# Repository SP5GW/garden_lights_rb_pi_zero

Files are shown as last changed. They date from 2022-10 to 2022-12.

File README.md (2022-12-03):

**<p style="text-align: center;">GardenPi - The Garden Light Controller</p>**

<p align="center">
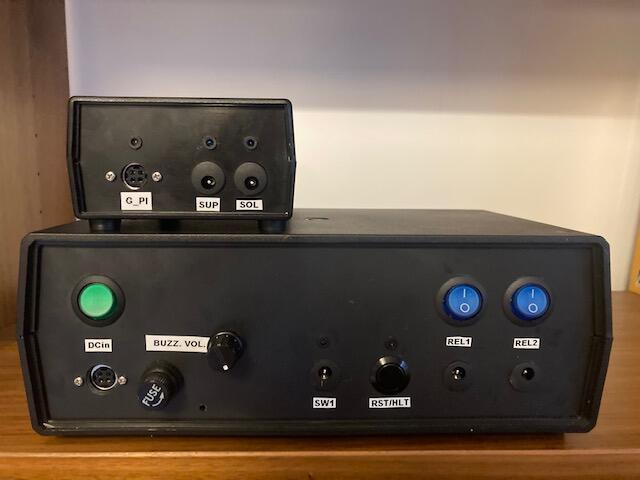
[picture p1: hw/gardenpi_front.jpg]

</p>

GardenPi is a Raspberry Pi Zero based two channel garden light controller, which includes hardware platform and systemd service written in python. Lights are automatically switched on/off based on calculated sunset time for provided location. Manual lights control is also supported. General information about status of the platform can be obtained from GUI and through cli command gardenpi, which also provides self diagnostics and remote logging configuration capabilities.

Platform is powered by:
<p align="left">
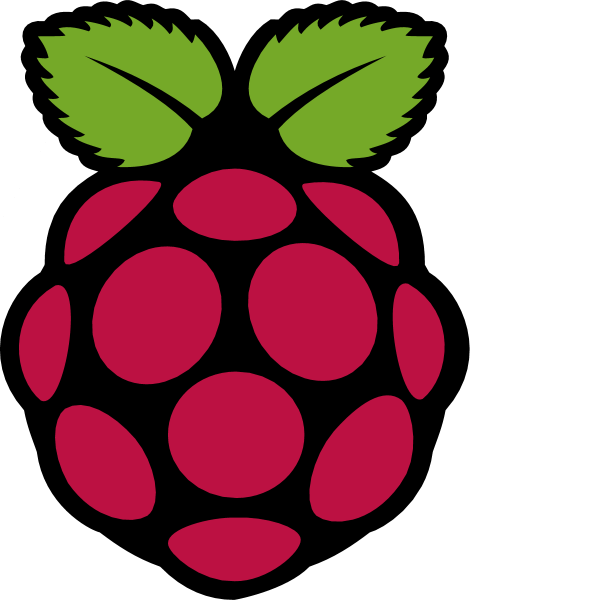
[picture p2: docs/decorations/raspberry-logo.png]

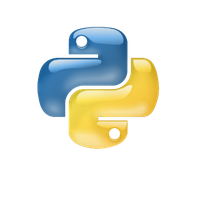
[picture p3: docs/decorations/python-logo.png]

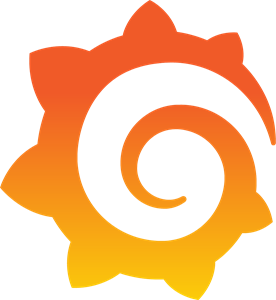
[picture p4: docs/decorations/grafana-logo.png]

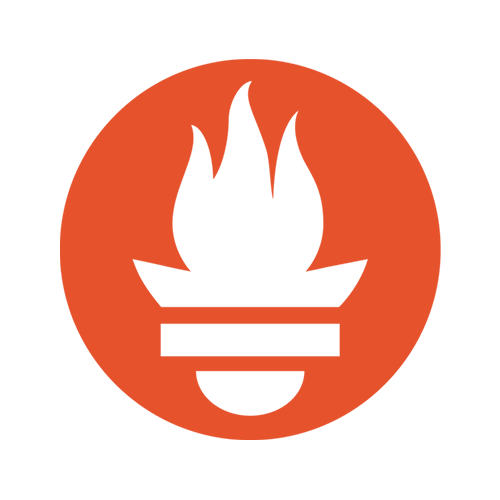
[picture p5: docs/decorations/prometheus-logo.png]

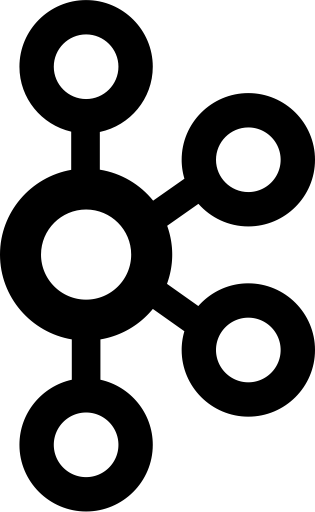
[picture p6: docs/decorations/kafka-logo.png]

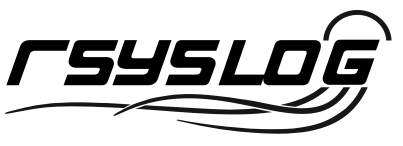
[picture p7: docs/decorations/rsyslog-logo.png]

</p>

**Key Features:**

- two software controlled relay 12V lighting channels with additional mechanical on/off switch (blue)
- main channel designated to control door lighting of the tool house
- secondary channel designated to control lighting of garden feature such as tree or sculpture
- both channels are switched on based on automatically calculated sunset time + predefined delay period
- main channel can be turned on with external on/off door switch as well
- configurable offset period controls delay between activation of main and secondary channel
- period when lights remain turned on can be configured separately for winter and summer time
- controller can be restarted by pressing Reset button
- controller can be shut down by toggling 5x the door switch within 1min interval
- door switch toggles are indicated by a beep.
- number of beeps correspond to the number of toggles, which occurred within 1min shutdown window
- after 1 min interval starting from the first switch on/off, toggle counter is reset to zero
- controller can be turned on and off by the green power switch
- when controller's boot sequence is finished after power on or restart, three short beeps are played 
- marked usb port can be used to ssh to the controller using cli command: ssh pi@gardenpi.local, pwd: raspberry
- wifi module is also configured and can be used whenever 2.4GHz wifi network is available
- real time is preserved at device shutdown using RTC module
- RTC module time is synchronized with network clock as soon as device is connected to LAN via Wi-Fi or USB
- Device is powered by 12V DC external power supplier (reversed polarity protection is implemented)
- Controller status is indicated by LED over RST/HLT button (steady/blinking - controller in operation)
- Grafana based simple GUI (dashboard) is available at http://gardenpi.local
- Simple unit diagnostics can be obtained by running command sudo gardenpi --test
- Buzzer volume can be controlled with potentiometer Buzz. Vol.
- Controller's syslog messages are forwarded to rsyslog server and kafka broker
- Remote logging enabled/configured/disabled using sudo gardenpi --logging option with parameters
- Power plug with additional digital line indicating source of power (solar vs. dc power supply) added
- Additional hardware unit switching automatically power source to dc power supply when battery voltage is too low released as a separate project (Solar / DC Backup Power Switch with Power Source Indicator). Unit is fully compatible with gardenpi controller version 5.0 and later.

**Design and Build Instructions**

HW design has been described in the following files:

* [Bill of Materials](./docs/gardenpi_bom.txt)
* [Circuit diagram](./docs/gardenpi_schematics.pdf)
* [HW Photos](./hw/)

Pi SW Image preparation process has been documented in the following command log file:

* SW Image Preparations command [log](./doc/gardenpi_cmd.txt).
* Latest stable SW image can be downloaded from [image repository](https://1drv.ms/u/s!AmoGY_QbIutmjDPu6R8zekghUcrf?e=fY6dYW)

Service python script, service file and initial configuration file storing service script settings are all located in:

* [Source Code Directory](./src)

All Pi configuration files, which were modified as part of this project are stored in:

* [Config Directory](./config)

**Initial Configuration**

* Connect GardenPi device to you linux host machine using usb cabel
* From host machine terminal ssh to GardenPi using following command:
	- ssh pi@gardenpi.local #password is set to: raspberry
* Modify solarcalc.ini  file with unit location information, all other parameters can be left at default.
	- nano ~/PyScripts/SolarCalc/solarcalc.ini
* Halt the device by toggling x5 door switch within 1min interval
* Unplug usb cable, place the device in target location and wire it to lighting and power source.
* If you need access to the list of config files and useful commands type gardenpi command.
* Enjoy the GardenPi device! :-)

**Device Operation**

Device does not require special maintenance, if GardenPi operates from location where there is no wifi access its RTC can drift so it is desirable to bring it within wifi coverage from time to time. Such behavior can be expected, but was not observed in real life yet.

**GUI**
Design of the GardenPi GUI has been detailed in gardenpi_gui.md document located in * [Docs Directory](./docs)
Grafana's dashboard has been specified in GardenPiController.json file located in * [Gui Directory](./gui)

GardenPi Dashboard:

<p align="center">
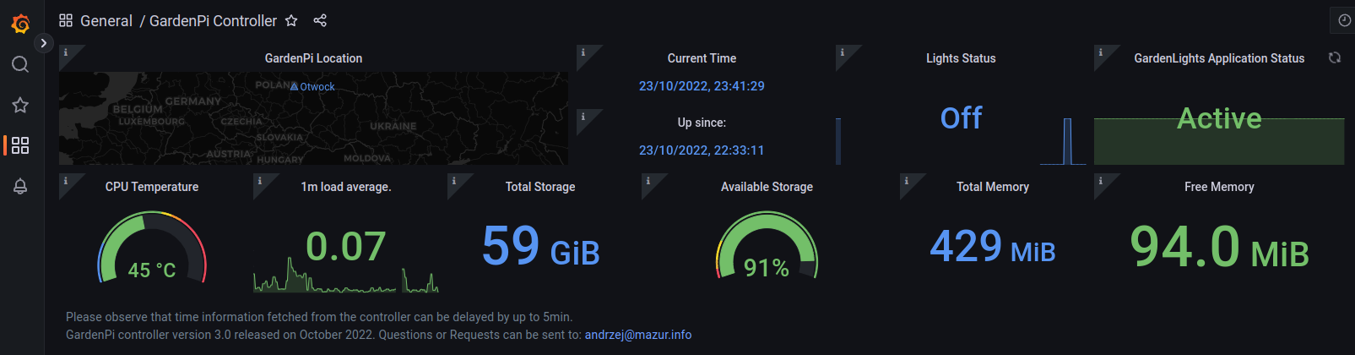
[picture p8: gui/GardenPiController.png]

</p>

**gardenpi command**
When connected to the terminal window over **ssh (user: pi@gardenpi.local, pwd: raspberry)**, it is possible to execute gardenpi command, which offers basic information about controller configuration.
To execute device selftest execute: **sudo gardenpi --test**

**Contributing**

* Fork it!
* Create your feature branch: git checkout -b my-new-feature
* Commit your changes: git commit -am 'Add some feature'
* Push to the branch: git push origin my-new-feature
* Submit a pull request

**Release History**

* Release 1.0 - October 2021 - basic functionality allowing light control
* Release 2.0 - October 2022 - new functionality:
	* device configuration via .ini file, 
	* buzzer support added, 
	* bug fixes focusing on stability (handling of shutdown procedure)
	* gardenpi command and device baner with useful configuration info added
* Release 3.0 - October 2022 - new functionality:
    * Grafana/Prometheus based GUI added
* Release 4.0 - October 2022 - new functionality:
	* 	buzzer volume control added
	* 	gardenpi command enhanced with device self-test routine
* Release 4.1 - November 2022 - new functionality and bug fixes:
	- possibility to set different lights-on durations for winter and summer times added
	- syslog messages are forwarded to rsyslog server and kafka broker
	- gardenpi command enhanced with remote logging configuration options
	* 	bug fix: depreciated zone function replaced in tzlocal with get_localtz_name() function call
	* 	bug fix: time presission correted in some info traces
* 	Release 5.0 December 2022 - new functionality:
	- 	Power connector changed to unique type, preventing accidental power cable incorrect insertion
	- 	Support for power source indicator (solar vs. power supply added)
	
**Planned Functionality**

* External WiFi antenna support
* Gardenpi service logging to syslog
* man page for gardenpi command

Comments or Questions can be directed to: andrzej@mazur.info

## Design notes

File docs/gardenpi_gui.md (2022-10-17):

# GardenPi GUI Implementation

<https://andrzejmazur2021.atlassian.net/wiki/spaces/~5ea827ff021ae30ba8e9fd23/pages/235470856/GardenPi+GUI+Implementation>

* * *

GardenPi GUI implementation is based on Grafana, Prometheus Node Exporter for arm v6 architecture and Prometheus Server. To screpe gardenlightsctrl.service Prometheus textfile data collector is used.



Due to current bug not allowing to change Grafana's TCP port number to 80 using grafana.ini file, port redirection from port 80 to 3000 using iptables has been configured instead.

## Prometheus Server Installation and Configuration

Check version of your arm architecture with: `cat /proc/cpuinfo`

```bash
cat cat /proc/cpuinfo
cat: cat: No such file or directory
processor	: 0
model name	: ARMv6-compatible processor rev 7 (v6l)
BogoMIPS	: 997.08
Features	: half thumb fastmult vfp edsp java tls 
CPU implementer	: 0x41
CPU architecture: 7
CPU variant	: 0x0
CPU part	: 0xb76
CPU revision	: 7

Hardware	: BCM2835
Revision	: 9000c1
Serial		: 00000000148e772f
Model		: Raspberry Pi Zero W Rev 1.1
```

In case of Pi Zero this is ARMv6.

Download Prometheus Server for your architecture from: [https://prometheus.io/download/](https://prometheus.io/download/) to your host machine, then copy it to your Pi Zero platform/PiGarden controller:

`scp /home/pi/Downloads/prometheus-2.39.1.linux-armv6.tar.gz pi@gardenpi.local:/home/pi`

Update all packages installed on the platform:

```bash
sudo apt update
apt list --upgradable
sudo apt upgrade
sudo shutdown -r now 
```

Extract the binaries outside of the archive you downloaded, move extracted directory to target location named `~/prometheus` and delete gz archive:

```bash
tar xfz prometheus-2.39.1.linux-armv6.tar.gz
mv prometheus-2.39.1.linux-armv6 prometheus
rm prometheus-2.39.1.linux-armv6.tar.gz
```

Create prometheus service file:

`sudo nano /etc/systemd/system/prometheus.service`

with following contents:

```bash
[Unit]
Description=Prometheus Server
Documentation=https://prometheus.io/docs/introduction/overview/
After=network-online.target

[Service]
User=pi
Restart=on-failure

ExecStart=/home/pi/prometheus/prometheus \
  --config.file=/home/pi/prometheus/prometheus.yml \
  --storage.tsdb.path=/home/pi/prometheus/data

[Install]
WantedBy=multi-user.target
```

Upon starting up, it will run the Prometheus executable located at “`/home/pi/prometheus/prometheus`“.

We pass in both the config file location and a storage location for the database that the monitoring software requires.

If you ever need to modify the config file, you can find it at “`/home/pi/prometheus/prometheus.yml`“.

Make prometheus service starting when Pi boots, then start the service manually and check its status:

```bash
sudo systemctl enable prometheus
sudo systemctl start prometheus
sudo systemctl status prometheus
```

Test prometheus service installation using curl:

## Prometheus Node Exporter Installation and Configuration

This time we use apt package installer to install Prometheus Node Exporter package:

```bash
sudo apt-get install prometheus-node-exporter
apt list --upgradable
sudo apt upgrade
```

Prometheus Node Exporter service file can be found at:

`/lib/systemd/system/prometheus-node-exporter.service`

Prometheus by default listens on port 9090, but we are interested in metricises from node exporter, which broadcasts data it scrapas on port 9100. That is why we need to reconfigure port number Prometheus Sever listens to and set it to 9100. This is done by the following modification of `~/prometheus/prometheus.yml` file in the following three areas:

```bash
global:
  #scrape_interval: 15s # Set the scrape interval to every 15 seconds. Default is every 1 minute.
  #evaluation_interval: 15s # Evaluate rules every 15 seconds. The default is every 1 minute.

  scrape_interval: 3s # Set the scrape interval to every 3 seconds. Default is every 1 minute.
  evaluation_interval: 3s # Evaluate rules every 3 seconds. The default is every 1 minute.

```

```bash
scrape_configs:
  # The job name is added as a label `job=<job_name>` to any timeseries scraped from this config.
  - job_name: "raspi"
```

```bash
    static_configs:
      #- targets: ["localhost:9090"]
      - targets: ["localhost:9100"]
```

To confirm that Prometheus Server is now receiving metrics' from Node Exporter execute the following command, which shall received cpu related metrics’:

```bash
curl http://localhost:9100/metrics | grep node_thermal_zone_temp
  % Total    % Received % Xferd  Average Speed   Time    Time     Time  Current
                                 Dload  Upload   Total   Spent    Left  Speed
100  130k    0  130k    0     # HELP node_thermal_zone_temp Zone temperature in Celsius
0 # TYPE node_thermal_zone_temp gauge
 node_thermal_zone_temp{type="cpu-thermal",zone="0"} 64.27
 529k      0 --:--:-- --:--:-- --:--:--  529k
```

If port Prometheus Server listens to is not changed correctly then no node\_ metrics' will be possible to fetch with curl…

Since we will need to report some gardenpi specific metrics' generated by `gardenlightsctrl.service` lets use for it textfile data collector of Prometheus Node Exporter. This collector is enabled by default and it scrapes all metrics' from files with .prom extension, which are located in the following directory:

`/var/lib/prometheus/node-exporter/`

More information regarding this data collector is available at: [https://github.com/prometheus/node\_exporter](https://github.com/prometheus/node_exporter)

To store metrics' specific to gardenpi lets create the following .prom file and make a symbolic link to it from `/var/lib/prometheus/node-exporter/` directory:

```bash
touch /home/pi/PyScripts/SolarCalc/solarcalc.prom
sudo ln ./solarcalc.prom /var/lib/prometheus/node-exporter/gardenpi.prom
```

Update contents of created solarcalc.prom file with simple test matrics:

`nano /home/pi/PyScripts/SolarCalc/solarcalc.prom`

```bash
# HELP gardenpi_lights_state Lights on/off indicator.
# TYPE gardenpi_lights_state gauge
gardenpi_lights_state 1
```

To verify that gardenpi metrics' are exposed to Prometheus Server:

```bash
ls -al /var/lib/prometheus/node-exporter/
total 12
drwxr-xr-x 2 root       root       4096 Oct 16 21:43 .
drwxr-xr-x 3 prometheus prometheus 4096 Oct 16 17:43 ..
-rw-r--r-- 1 root       root        397 Oct 16 21:43 apt.prom
-rw-r--r-- 2 pi         pi            0 Oct 16 21:41 gardenpi.prom
```

```bash
curl http://localhost:9100/metrics | grep gardenpi
  % Total    % Received % Xferd  Average Speed   Time    Time     Time  Current
                                 Dload  Upload   Total   Spent    Left  Speed
100  3944    0  3944    0     0   2409      0 --:--:--  0:00:01 --:--:--  2410# HELP gardenpi_lights_state Lights on/off indicator.
# TYPE gardenpi_lights_state gauge
gardenpi_lights_state 1
node_textfile_mtime_seconds{file="gardenpi.prom"} 1.66594986e+09
100  115k    0  115k    0     0  67378      0 --:--:--  0:00:01 --:--:-- 67378
node_uname_info{domainname="(none)",machine="armv6l",nodename="gardenpi",release="5.15.61+",sysname="Linux",version="#1579 Fri Aug 26 11:08:59 BST 2022"} 1
```

## Grafana Installation (RB PI4)

Add the APT key used to authenticate packages:

`wget -q -O - https://packages.grafana.com/gpg.key | sudo apt-key add -`

Add the Grafana APT repository:

`echo "deb https://packages.grafana.com/oss/deb stable main" | sudo tee -a /etc/apt/sources.list.d/grafana.list`

Install Grafana:

```bash
sudo apt-get update
sudo apt-get install -y grafana
```

Enable the Grafana server so it always starts after gardenpi is booted:

`sudo systemctl enable grafana-server`

Start the Grafana server:

```bash
sudo systemctl start grafana-server
sudo systemctl status grafana-server
```

Grafana is now running on the machine and is accessible from any device on the local network. it is accessible from host machine browser under the address: `gardenpi.local:3000`

Default grafana’s login credentials to be used during first login are: user: admin, password: admin

## Grafana Installation (RB PI Zero)

Uninstall grafana package installed with apt package manager (with all config files):

```bash
sudo apt purge grafana
sudo rm -rf /etc/grafana
```

Execute installation procedure from grafana web page for arm6 version: [https://grafana.com/grafana/download?platform=arm](https://grafana.com/grafana/download?platform=arm)

```bash
sudo apt-get install -y adduser libfontconfig1
wget https://dl.grafana.com/enterprise/release/grafana-enterprise-rpi_9.2.0_armhf.deb
sudo dpkg -i grafana-enterprise-rpi_9.2.0_armhf.deb
```

Enable the Grafana server so it always starts after gardenpi is booted:

```bash
sudo systemctl daemon-reload
sudo systemctl enable grafana-server
```

Start the Grafana server:

```bash
sudo systemctl start grafana-server
sudo systemctl status grafana-server
```

Grafana is now running on the machine and is accessible from any device on the local network. it is accessible from host machine browser under the address: `gardenpi.local:3000`

Default grafana’s login credentials to be used during first login are: user: admin, password: admin

At first login password has to be changed for admin user. new password is set to raspberry.

## Grafana Configuration

Due to current bug not allowing to change Grafana's TCP port number to 80 using grafana.ini file, port redirection from port 80 to 3000 using iptables has been configured instead.

iptables rules allowing grafana gui to be reached from browser on http port 80 following rules needs to be added:

redirection from outside world:  
`sudo iptables -A PREROUTING -t nat -i wlan0 -p tcp --dport 80 -j REDIRECT --to-port 3000`

redirection on the same machine:  
`sudo iptables -t nat -A OUTPUT -o lo -p tcp --dport 80 -j REDIRECT --to-port 3000`

In order to save new iptables rules `iptables-persistent` package has to be installed:

`sudo apt-get install iptables-persistent`

To list currently defined iptables rules for ipv4:

`nano /etc/iptables/rules.v4`

Content of above file after implementing port 80 to 3000 redirection:

```bash
# Generated by iptables-save v1.8.7 on Sun Oct 16 23:55:46 2022
*nat
:PREROUTING ACCEPT [0:0]
:INPUT ACCEPT [0:0]
:OUTPUT ACCEPT [0:0]
:POSTROUTING ACCEPT [0:0]
-A PREROUTING -i wlan0 -p tcp -m tcp --dport 80 -j REDIRECT --to-ports 3000
-A OUTPUT -o lo -p tcp -m tcp --dport 80 -j REDIRECT --to-ports 3000
COMMIT
# Completed on Sun Oct 16 23:55:46 2022
```

After adding new rules either directly to the file abbove `COMMIT` line or through `iptables` command. The new rules set can be saved with:

```bash
sudo su -
root@raspberrypi:~# sudo iptables-save > /etc/iptables/rules.v4
root@raspberrypi:~# exit
```

Login to grafana’s gui:

```bash
http://gardenpi.local
user: admin
password: raspberry
```

Go to admin panel, click bottom left shield icon and define pi user with no admin privileges:

```bash
user: pi
password: raspberry
```

Go to configuration, data sources and select Prometheus.

From Prometheus Datasource configuration panel the only place to make an adjustment is Prometheus server address:



Go to Dashboards, new, import and select to import from json file. Point at `./gui/GardenPiController.json`

Set imported gui as favourite (star in top left section of the gui)

Got to Configuration, Preferences and set home dashboard to GardenPi/GardenPi Controller:



## References

[https://prometheus.io/docs/introduction/overview/](https://prometheus.io/docs/introduction/overview/)

[https://pimylifeup.com/raspberry-pi-prometheus/](https://pimylifeup.com/raspberry-pi-prometheus/)

[https://github.com/prometheus/node\_exporter](https://github.com/prometheus/node_exporter)

[https://grafana.com/tutorials/install-grafana-on-raspberry-pi/](https://grafana.com/tutorials/install-grafana-on-raspberry-pi/)

[https://grafana.com/grafana/download?platform=arm](https://grafana.com/grafana/download?platform=arm)

[https://blog.mxard.com/persistent-iptables-on-raspberry-pi-raspbian](https://blog.mxard.com/persistent-iptables-on-raspberry-pi-raspbian)

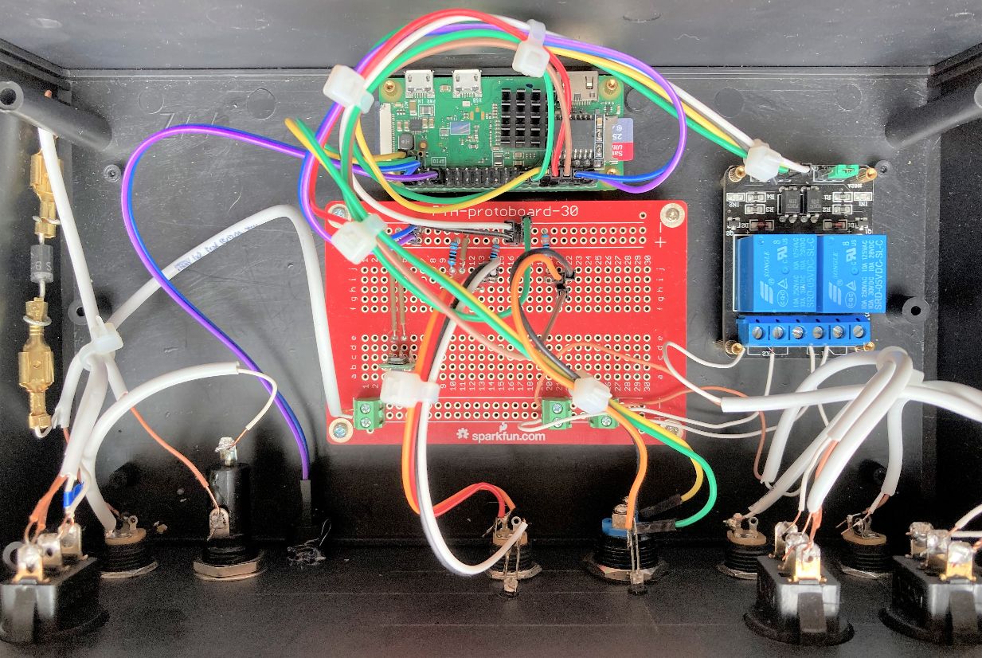
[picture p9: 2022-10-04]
hw/gardenpi_internal.jpg

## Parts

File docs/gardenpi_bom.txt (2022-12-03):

Bill of Materials for Gardenpi Rev 5.0

=============================================================================================================================
Device Type					Model						Qty	Seller:product code
=============================================================================================================================

Microcontroller					Raspberry Pi Zero W 512MB RAM - WiFi + BT 4.1	1	Botland: RPI-08330
Step Up/Down Voltage Regulator 5V 1.5A		Pololu 2836					1	Botland: PLL-08738
RTC Module + battery				DS3231 I2C Pi HAT				1	Botland: MOD-03790
Relay Module, 2 channels, 5V coil		Iduino 2					1	Botland: OST-14266
Active buzzer with generator 5V 12mm		unspecified					1	Botland: EAK-00786
Schottky diode 60V/5A				SB560						1       Botland: AKS-14591
Through Hole 3mm Short Lens Blue		Lumex SSL-LX3044USBC				2       Mouser: 696-SSL-LX3044USBC
Push Button Switch DC 12V, Illuminated (blue)	unspecified					2       AVT: 14 78521
Push Button S with DC 12V, Illuminated (green)	unspecified					1       AVT: 13 78520
Momentary Push Button										1
Fuse holder 6x30mm				GBZ30						1       Botland: KAB-05474
Fuse WTA 5x20mm - 250V/1A			unspecified					1       Botland: KAB-05465
DC Barrel Jack - 5.5x2.1mm, Panel Mount		2179						4	Botland: KAB-09351
Plastic Bevel LED Holder 3mm			Adafruit accessories				2       Mouser: 485-2179
SD Card						Scandisk 64G					1
Black Chassie 148x250x90mm			Kradex Z15					1	Botland: KDX-05774
Radiators for Pi CPU				unspecified					1	Botland: MOD-09871
Accessories Solder-able Breadboard		SparkFun PRT-12070				1	Mouser: 474-PRT-12070
Resistor					1k						1
Resistor					10k						1
Resistor					220						1
Resistor					330						1
Resistor Trimmer				1k						1
Resistor Variable				1k, A (logarythmic) 				1
Transistor NPN					2N2222						1
Knob												1
LED						3mm, blue					2
Round Rocker SPST Toggle Switch			DC 12V 20A,ON/OFF,Blue LED, fits 20,5mm hole	2
Round Rocker SPST Toggle Switch			DC 12V 20A,ON/OFF,Green LED, fits 20,5mm hole	1
Kycon DC Power Connector			KPPX-4P						1	Mouser: 806-KPPX-4P
Kycon DC Power Connector			KPJX-PM-4S-S					1	Mouser: 806-KPJX-PM-4S-S
4 wire installation cable			50cm, OMY4x0,75,H03VVH2-F 			1	Allegro/digma_pl					
screws M2x20					length: 20mm, diameter: M2 (2mm)		2 	Allegro/jack20prv
nuts M2						diameter:M2 (2mm)				2	Allegro/jack20prv

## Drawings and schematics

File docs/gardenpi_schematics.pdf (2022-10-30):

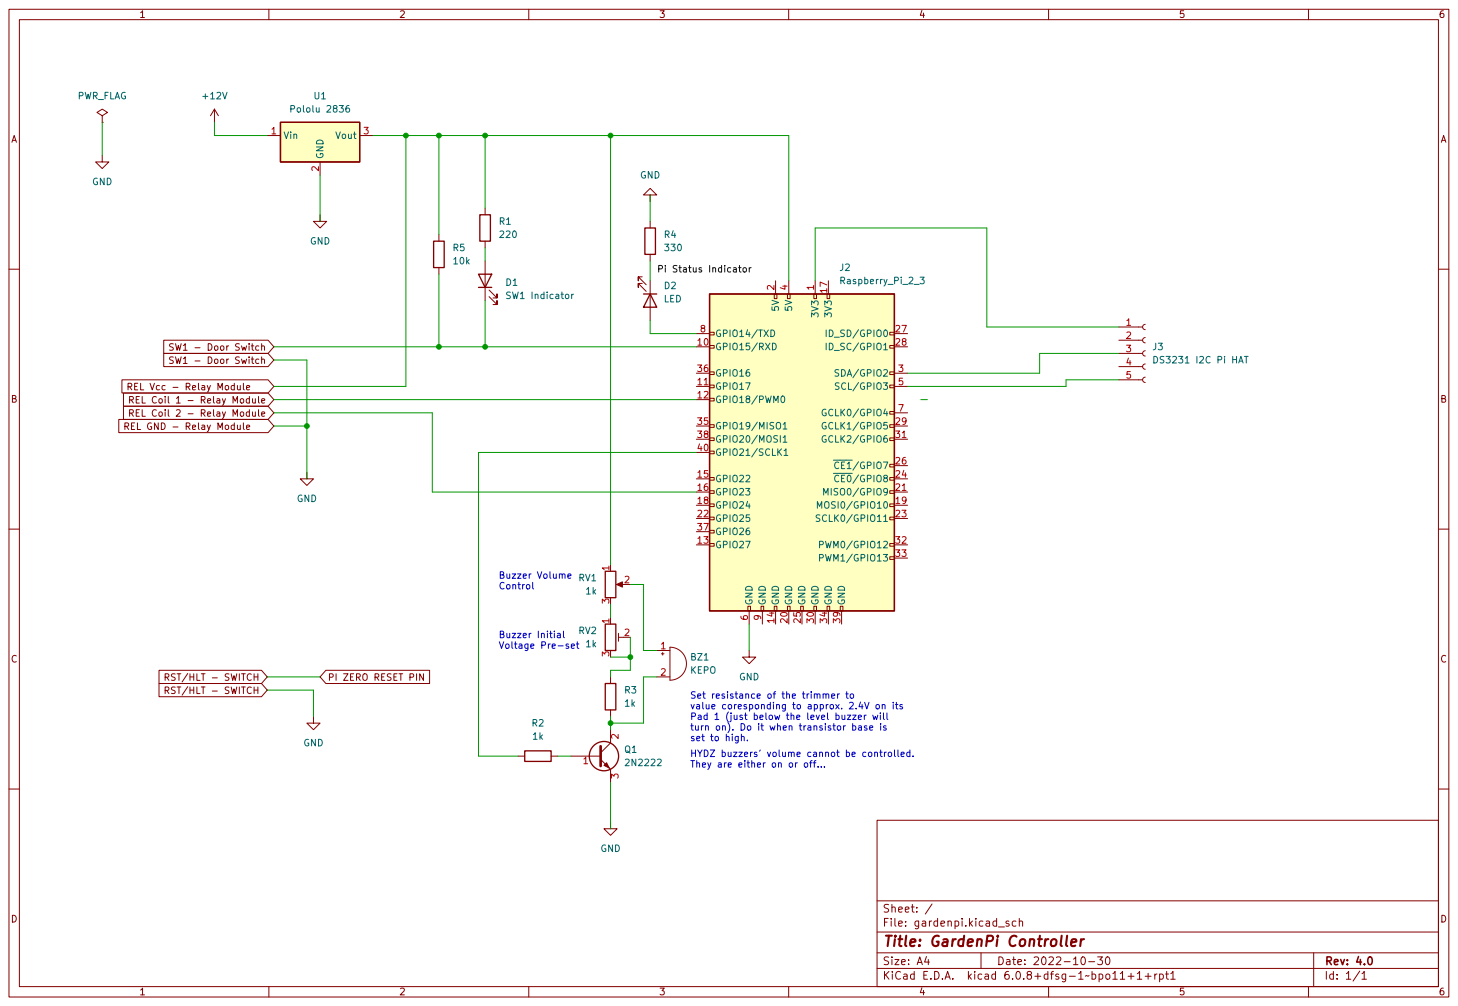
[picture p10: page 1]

Pi Status Indicator HYDZ buzzers' volume cannot be controlled. They are either on or off... Set resistance of the trimmer to value coresponding to approx. 2.4V on its

2 Vout 3 U1 Pololu 2836 GND GND

J2Raspberry_Pi_2_3 GND
REL Vcc - Relay Module RST/HLT - SWITCH
REL Coil 1 - Relay Module

SW1 - Door Switch REL Coil 2 - Relay Module

J3DS3231 I2C Pi HAT GND GND

set to high. Buzzer Volume Control Buzzer Initial Voltage Pre-set

Pad 1 (just below the level buzzer will
turn on). Do it when transistor base is

Id: 1/1 Title: GardenPi Controller

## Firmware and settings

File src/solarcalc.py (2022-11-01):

#!/usr/bin/python3

#sudo apt-get install python3-pip

import datetime
import time
import tzlocal # pip3 install tzlocal 
import astral # pip3 install astral
from astral.sun import sun
import pause # pip3 install pause
import RPi.GPIO as GPIO
from threading import Thread
import signal
import os
import logging
import sys
import configparser

#define default values for parameters defined in solarcalc.ini file.
defaults_ini = {
    'city':'Otwock',
    'country':'Poland',
    'latitude':'52°06′N',
    'longitude':'21°15′E',
    'lights_on_delay':'30',
    'lights_on_duration_summer':'2',
    'lights_on_duration_winter':'4',
    'log_to_file':'False',
    'log_all':'False'
   }


#build .ini file path - to be stored in same location as source file
idx=os.path.split(os.path.basename(__file__))[1].find('.')
file_name_wo_extension=os.path.split(os.path.basename(__file__))[1][:idx]
ini_file_path = os.path.dirname(os.path.realpath(__file__)) + "/" + file_name_wo_extension + ".ini"

#define .ini file to be parsed
iconfig_ini_file_path = ini_file_path 
config = configparser.ConfigParser(defaults_ini)
config.read(ini_file_path)

print ("Configuration file: ",ini_file_path, " successfuly opened.")

#Global variable informing button handling thread about state of main thread
thread_exit = False

# Define pin GPIO15 to control button1
button_ctrl_pin = 15

# Define pin GPIO18 to control relay coil 
relay_ctrl_pin1 = 18
# Define pin GPIO14 to control relay coil 
relay_ctrl_pin2 = 23 #originally 14

# Define pin GPIO21 to control buzzer 
buzzer_ctrl_pin = 21

# Sunset lights on/off status (timer controlled)
glb_sunset_lights_on = False

#Set debug to True in order to log all messages!
#LOG_ALL = False
LOG_ALL = config.getboolean('logging','log_all')
#Set log_to_file flag to False in order to print logs on stdout
#LOG_TO_FILE = False
LOG_TO_FILE = config.getboolean('logging','log_to_file')

#create two log file handlers, one for actual log file and another for stdout
stdout_handler = logging.StreamHandler(sys.stdout)

if LOG_TO_FILE == True:
    #extract file name from filename.extension
    idx=os.path.split(os.path.basename(__file__))[1].find('.')
    file_name_wo_extension=os.path.split(os.path.basename(__file__))[1][:idx]
    log_file = os.path.dirname(os.path.realpath(__file__)) + "/" + file_name_wo_extension + ".log"
    file_handler = logging.FileHandler(filename=log_file)
    hndls = [file_handler]
    print ("Program logs are stored in: ", log_file)
else:
    hndls = [stdout_handler]
        
#configure logger module
#levels: DEBUG,INFO,WARNING,ERROR,CRITICAL
#LOG_ALL = TRUE means that all log messages are printed out
#LOG_ALL = FALSE means that DEBUG logs are not printed

if LOG_ALL == True:
    logging.basicConfig(level = logging.DEBUG,format = '%(asctime)s:%(threadName)s:%(filename)s:%(lineno)s:%(levelname)s:%(message)s', handlers=hndls)
else:
    logging.basicConfig(level = logging.INFO,format = '%(asctime)s:%(threadName)s:%(filename)s:%(lineno)s:%(levelname)s:%(message)s', handlers=hndls)

logging.debug('Loaded logging parameters:')
logging.debug('      Log All Information Incl. DEBUG logs: %s', LOG_ALL)
logging.debug('      Log to File: %s', LOG_TO_FILE)

#build .prom file path - to be stored in same location as source file
idx=os.path.split(os.path.basename(__file__))[1].find('.')
file_name_wo_extension=os.path.split(os.path.basename(__file__))[1][:idx]
glb_prom_file_path = os.path.dirname(os.path.realpath(__file__)) + "/" + file_name_wo_extension + ".prom"

#prom_file_path is dynamically linked to:/var/lib/prometheus/node-exporter/gardenpi.prom
#node exporter's text file collector
logging.info('Prometheus node exporters textfile collector path: %s', glb_prom_file_path)

current_location_name = config.get('location','city')
current_location_region = config.get('location','country')
current_location_latitude = config.get('location','latitude')
current_location_longitude = config.get('location','longitude')

logging.debug('Loaded location parameters:')
logging.debug('      Name: %s', current_location_name)
logging.debug('      Country: %s', current_location_region)
logging.debug('      Latitude: %s', current_location_latitude)
logging.debug('      Longitude: %s', current_location_longitude)


def handleSIGTERM(signum, frame):
    global thread_exit
    global relay_ctrl_pin1
    global relay_ctrl_pin2
    print("Exiting the program, SIGTERM received...")
    thread_exit = True
    thread.join()
    GPIO.output(relay_ctrl_pin1,GPIO.HIGH) #turn off the relay1
    GPIO.output(relay_ctrl_pin2,GPIO.HIGH) #turn off the relay2
    exit(0)

# Define a function for button handling thread
def ButtonHandlingThread(button1_gpio_ctrl_pin):
    global thread_exit
    global relay_ctrl_pin1
    global relay_ctrl_pin2
    global glb_sunset_lights_on
    global glb_prom_file_path
    button_1 = False
    button_1_old = False
    loop_duration = 0.1 #in seconds
    counter_on = 0
    counter_off = 0
    counter_relay2_on_delay = 0
    counter_shutdown = 0 
    shutdown_window = 0
    shutdown_window_inc = 0
    lights_on = False
    lights_on_old = False
    
    logging.info('Starting Button Handling Thread!')
    while (True):
        if thread_exit == True:
            break
        time.sleep(loop_duration) # this sleep is to help ignoring button rebouncing 
        if GPIO.input(button1_gpio_ctrl_pin) == False:
            counter_off = 0
            if counter_on < 10:
                counter_on = counter_on + 1
            else:
                #logging.debug('Button1 = on')
                button_1 = True 
        else:
            counter_on = 0
            if counter_off < 10:
                counter_off = counter_off + 1
            else:
                #logging.debug('Button1 = off')
                button_1 = False
        if button_1 != button_1_old:
            if button_1:
                logging.debug('Button1 toggled to on!')
                logging.debug('    >shutdown_window: %s, loop_duration: %s, shutdown_window_inc: %s, counter_shutdown: %s',str(shutdown_window), str(loop_duration),str(shutdown_window_inc),str(counter_shutdown))             

                if shutdown_window <= (60 / loop_duration): #1min window to turn on/off button 5 times
                    shutdown_window_inc = 1
                    counter_shutdown = counter_shutdown + 1
                    #Play a sound to indicate gardenpi light switch is toggled within shutdown window
                    #If number of short beeps is 5 then shutdown will follow
                    BuzzerSound(1,counter_shutdown)
                else: 
                    shutdown_window_inc = 0
                    shutdown_window = 0
                    #Bug correction
                    #counter_shutdown = 0
                    counter_shutdown = 1
                    BuzzerSound (1,1)
                    logging.debug('More then 1min elapsed from last light switch on/off toggle - shutdown window has been reset...')
                    
                logging.debug('   >>shutdown_window: %s, loop_duration: %s, shutdown_window_inc: %s, counter_shutdown: %s',str(shutdown_window), str(loop_duration),str(shutdown_window_inc),str(counter_shutdown))  

                if counter_shutdown >= 5: #shutdown system if button is pressed 5 times within 1min
                    logging.info('Light switch toggled on/off 5x in 1min - initiating system shutdown !!!')
                    #Play single long beep to indicate gardenpi is about to shutdown!
                    BuzzerSound(2,0)
                    counter_shutdown = 0
                    os.system("sudo shutdown -h now")
            else:
                logging.debug('Button1 toggled to off!')
                
            button_1_old = button_1
            
        if glb_sunset_lights_on == True or button_1 == True:
            #Turn on relay 1
            GPIO.output(relay_ctrl_pin1,GPIO.LOW)
            lights_on = True
        else:
            #Turn off relay 1
            GPIO.output(relay_ctrl_pin1,GPIO.HIGH)
            lights_on = False
         
        if glb_sunset_lights_on == True and counter_relay2_on_delay >= 100:
            #Turn on relay 2
            GPIO.output(relay_ctrl_pin2,GPIO.LOW)
        elif glb_sunset_lights_on == True:
            counter_relay2_on_delay = counter_relay2_on_delay + 1
        else:
            #Turn off relay 2
            GPIO.output(relay_ctrl_pin2,GPIO.HIGH)
            counter_relay2_on_delay = 0

        if shutdown_window > (180 / loop_duration): # window in sec / loop_duration (i.e. duration of one loop)
            logging.debug('More then 3min elapsed from last light switch on/off toggle - shutdown window has been reset...')
            logging.debug('  >shutdown_window: %s, shutdown_window_max: %f', shutdown_window, 180 / loop_duration)
            shutdown_window_inc = 0
            shutdown_window = 0
            counter_shutdown = 0

        shutdown_window = shutdown_window + shutdown_window_inc
        #logging.debug('shutdown_window_inc =%s, shutdown_window = %s',shutdown_window_inc, shutdown_window)
        
        if lights_on == True and lights_on_old == False:
            # lights have been switched on
            PromMetrixUpdateLightsState(glb_prom_file_path, 1)
            lights_on_old = True
        elif lights_on == False and lights_on_old == True:
            # lights have been switched off
            PromMetrixUpdateLightsState(glb_prom_file_path, 0)
            lights_on_old = False
            

#Define buzzer sound
def BuzzerSound(SoundType,Repeat):

    GPIO.setup(buzzer_ctrl_pin,GPIO.OUT)
    
    if (SoundType==1):
        #Multiple Short Beeps
        for y in range (Repeat):
            for x in range(3):
                GPIO.output(buzzer_ctrl_pin,GPIO.HIGH)
                time.sleep(0.01)
                GPIO.output(buzzer_ctrl_pin,GPIO.LOW)
                time.sleep(0.01)
            time.sleep(0.5)
    elif SoundType == 2:
        #Single Long Beep
        #Repeat parameter ignored
            time.sleep(0.8)
            for x in range(20):
                GPIO.output(buzzer_ctrl_pin,GPIO.HIGH)
                time.sleep(0.01)
                GPIO.output(buzzer_ctrl_pin,GPIO.LOW)
                time.sleep(0.01)
    else:
        print('')
        #Undefined sound
        
# Set Values in Prometheus node exporter's text collector file
def PromMetrixSet(prom_file_p, loc_country, loc_city, loc_lat, loc_lon, lights_state): 
#It is assumed that PromMetrixSetLocation is always called prior to
#PromMetrixUpdate function
    
    locstr = "gardenpi_location{country=\"%s\",city=\"%s\",latitude=\"%s\",longitude=\"%s\"} 0\n" % (loc_country, loc_city, loc_lat, loc_lon)
    
    if os.path.exists(prom_file_p):
        #gardenpi_location{country="Poland",city="Otwock",latitude="52",longitude="21"} 0
        #gardenpi_lights_state ligths_state
        logging.debug('Prometheus node exporters textfile already exist - modifying it with:')
        logging.debug('   gardenpi_lights_state %s', lights_state)
        logging.debug('   %s', locstr)

        prom_file = open(prom_file_p,'r')
        filedata = prom_file.readlines()
        prom_file.close()
    
        prom_file = open(prom_file_p,'w')

        filedata[6] = locstr

        if lights_state == 0:
            #replace value 0 with 1
            filedata[2] = "gardenpi_lights_state 0\n"
        else:
            #replace value 1 with 0
            filedata[2] = "gardenpi_lights_state 1\n"
            
        prom_file.writelines(filedata)
        prom_file.close()
    
    else:
        logging.debug('Prometheus node exporters textfile does not exist - creating it with:')
        logging.debug('   gardenpi_lights_state %s', lights_state)
        logging.debug('   %s', locstr)

        prom_file = open(prom_file_p,'w')
        prom_file.write('# HELP gardenpi_lights_state Lights on/off indicator.\n')
        prom_file.write('# TYPE gardenpi_lights_state gauge\n')

        if lights_state  == 0:
            prom_file.write('gardenpi_lights_state 0\n')
        else:
            prom_file.write('gardenpi_lights_state 1\n')
            
        prom_file.write('\n')
        
        prom_file.write('# HELP gardenpi_location Information about geographical location of gardenpi controller\n')
        prom_file.write('# TYPE gardenpi_location gauge\n')
        prom_file.write(locstr)
        
        prom_file.close()

# Update Light State value in Prometheus node exporter's collector file
def PromMetrixUpdateLightsState(prom_file_p, value): 
#It is assumed that PromMetrixSetLocation is always called prior to this function!
#i.e. prom_file must already exist before this function is called 
    if os.path.exists(prom_file_p):
        
        logging.debug('Prometheus node exporters textfile already exist - modifying it with:')
        logging.debug('   gardenpi_lights_state %s', value)

        prom_file = open(prom_file_p,'r')
        filedata = prom_file.read()
        
        prom_file.close()
    
        prom_file = open(prom_file_p,'w')

        if value == 0:
            filedata = filedata.replace('gardenpi_lights_state 1','gardenpi_lights_state 0')
        else:
            filedata = filedata.replace('gardenpi_lights_state 0','gardenpi_lights_state 1')
            
        prom_file.write(filedata)
        prom_file.close()
    
    else:
        logging.debug('Prometheus node exporters textfile does not exist - creating it with:')
        logging.debug('   gardenpi_lights_state %s', value)

        prom_file = open(prom_file_p,'w')
        prom_file.write('# HELP gardenpi_lights_state Lights on/off indicator.\n')
        prom_file.write('# TYPE gardenpi_lights_state gauge\n')

        if value == 0:
            prom_file.write('gardenpi_lights_state 0\n')
        else:
            prom_file.write('gardenpi_lights_state 1\n')
            
        prom_file.close()

GPIO.setmode(GPIO.BCM)
GPIO.setwarnings(False)
GPIO.setup(relay_ctrl_pin1,GPIO.OUT)
GPIO.output(relay_ctrl_pin1,GPIO.HIGH) #turn off the relay1
GPIO.setup(relay_ctrl_pin2,GPIO.OUT)
GPIO.output(relay_ctrl_pin2,GPIO.HIGH) #turn off the relay2

signal.signal(signal.SIGTERM, handleSIGTERM)

current_datetime_local = datetime.datetime.now().astimezone()

# Issue corrected use of depreciated zone function
# depreciated tzlocal.get_localzone().zone changed to tzlocal.get_localzone_name()
#current_time_zone = tzlocal.get_localzone().zone
current_time_zone = tzlocal.get_localzone_name()

current_datetime_utc = datetime.datetime.utcnow()

logging.info (' ')

logging.info ('Platform local time is now: %s', str(current_datetime_local.ctime()))
logging.info ('Platform universal time is now: %s', str(current_datetime_utc.ctime()))

logging.info (' ')

#Play 3 short beeps to indicate gardenpi is up and booted!
BuzzerSound(1,3)


#Report location and initial lights status 
PromMetrixSet(glb_prom_file_path, current_location_region, current_location_name, current_location_latitude.split("°")[0], current_location_longitude.split("°")[0], (int)(glb_sunset_lights_on))

#Start button handling thread
GPIO.setmode(GPIO.BCM)
GPIO.setwarnings(False)
GPIO.setup(button_ctrl_pin,GPIO.IN)

thread = Thread(target = ButtonHandlingThread, name = "ButtonHndlThread", args = (button_ctrl_pin,))
thread.start()


next_sunset_datetime_local = current_datetime_local


while True: #endless loop

    current_location = astral.LocationInfo(current_location_name, current_location_region,current_time_zone, current_location_latitude, current_location_longitude)

    s = sun(current_location.observer, next_sunset_datetime_local.date(), tzinfo=current_time_zone)

    current_location_dawn = s["dawn"]
    current_location_sunrise = s["sunrise"]
    current_location_noon = s["noon"]
    current_location_sunset = s["sunset"]
    current_location_dusk = s["dusk"]

    #print ("Sun information for: " + current_location_name + "," + current_location_region + "(" + current_location_latitude + "," + current_location_longitude + "), on " + str(next_sunset_datetime_local.strftime("%m/%d/%Y")) + ":") 

    logging.info('Sun information for: %s, %s(%s,%s) on %s:',current_location_name,current_location_region,current_location_latitude,current_location_longitude,str(next_sunset_datetime_local.strftime("%m/%d/%Y")))

    #current_location_sunset = datetime.datetime(2021,6,28,20,20) # for test only

    logging.info ('  sunrise: %s', current_location_sunrise.strftime ("%H:%M %Z"))
    logging.info ('  sunset: %s', current_location_sunset.strftime("%H:%M %Z"))


    logging.info (' ')
    
    offset_lights_on_ini = config.getint('timers','lights_on_delay')
    
    #offset_lights_off_ini = config.getint('timers','lights_on_duration')
    offset_lights_off_summer_ini = config.getint('timers','lights_on_duration_summer')
    offset_lights_off_winter_ini = config.getint('timers','lights_on_duration_winter')

    if (time.localtime().tm_isdst ==0):
        #DST not in the effect, use winter time lights-on duration
        offset_lights_off = offset_lights_off_winter_ini
    else:
        #DST not in the effect, use winter time lights-on duration
        offset_lights_off = offset_lights_off_summer_ini
    
    logging.debug('Loaded Lights timer parameters:')
    logging.debug('      Lights On Delay: %s min',offset_lights_on_ini )
    logging.debug('      Lights On Duration: %s h', offset_lights_off)

    time_offset_lights_on = datetime.timedelta(minutes=offset_lights_on_ini) #offset = 30
    time_offset_lights_off = time_offset_lights_on + datetime.timedelta(hours=offset_lights_off)

    current_location_lights_on = current_location_sunset + time_offset_lights_on
    current_location_lights_off = current_location_sunset + time_offset_lights_off
    current_location_lights_off = current_location_lights_off.astimezone()
    
    logging.info('Lights will be switched on at:  %s', current_location_lights_on.strftime("%H:%M %Z"))
    logging.info('Lights will be switched off at: %s', current_location_lights_off.strftime("%H:%M %Z"))

    logging.info(' ')
    logging.info('Waiting until the time when lights will be switched on!')
    pause.until(current_location_lights_on)
    glb_sunset_lights_on = True
    logging.info('Lights has been switched on!')
    pause.until(current_location_lights_off)
    glb_sunset_lights_on = False
    logging.info('Lights has been switched off!')
    logging.info(' ')

    #midnight datetime calculated for the day when last switch on/off cycle started at
    today_midnight_datetime = datetime.datetime.combine(current_datetime_local.date(),datetime.time(23,59))
    today_midnight_datetime = today_midnight_datetime.astimezone()
    
    #current date refreshed after last switch on/off cycle has finished
    current_datetime_local = datetime.datetime.now().astimezone()
    
    #issue corrected time printed with too high precission
    #logging.info('current_datetime_local =  %s',str(current_datetime_local))
    #logging.info('today_midnight_datetime =  %s',str(today_midnight_datetime))
    #logging.info('current_location_lights_off = %s',str(current_location_lights_off))
    logging.info('current_datetime_local =  %s',current_datetime_local.ctime())
    logging.info('today_midnight_datetime =  %s',today_midnight_datetime.ctime())
    logging.info('current_location_lights_off = %s',current_location_lights_off.ctime())


    if current_datetime_local <= today_midnight_datetime:
        logging.info('Lights were already switched on/off after sunset - making calculations for tommorow')
        next_sunset_datetime_local = current_datetime_local + datetime.timedelta(days=1)
        next_sunset_datetime_local = datetime.datetime.combine(next_sunset_datetime_local.date(),datetime.time(0,5))
        logging.info(  '%s', str(next_sunset_datetime_local))
    else:
        logging.info('Making calculations for todays sunrise/sunset...')
        next_sunset_datetime_local = current_datetime_local
    logging.info(' ')

thread_exit = True
thread.join()

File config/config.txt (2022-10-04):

# For more options and information see
# http://rpf.io/configtxt
# Some settings may impact device functionality. See link above for details

# uncomment if you get no picture on HDMI for a default "safe" mode
#hdmi_safe=1

# uncomment the following to adjust overscan. Use positive numbers if console
# goes off screen, and negative if there is too much border
#overscan_left=16
#overscan_right=16
#overscan_top=16
#overscan_bottom=16

# uncomment to force a console size. By default it will be display's size minus
# overscan.
#framebuffer_width=1280
#framebuffer_height=720

# uncomment if hdmi display is not detected and composite is being output
#hdmi_force_hotplug=1

# uncomment to force a specific HDMI mode (this will force VGA)
#hdmi_group=1
#hdmi_mode=1

# uncomment to force a HDMI mode rather than DVI. This can make audio work in
# DMT (computer monitor) modes
#hdmi_drive=2

# uncomment to increase signal to HDMI, if you have interference, blanking, or
# no display
#config_hdmi_boost=4

# uncomment for composite PAL
#sdtv_mode=2

#uncomment to overclock the arm. 700 MHz is the default.
#arm_freq=800

# Uncomment some or all of these to enable the optional hardware interfaces
dtparam=i2c_arm=on
#dtparam=i2s=on
#dtparam=spi=on

# Uncomment this to enable infrared communication.
#dtoverlay=gpio-ir,gpio_pin=17
#dtoverlay=gpio-ir-tx,gpio_pin=18

# Additional overlays and parameters are documented /boot/overlays/README

# Enable audio (loads snd_bcm2835)
dtparam=audio=on

# Automatically load overlays for detected cameras
camera_auto_detect=1

# Automatically load overlays for detected DSI displays
display_auto_detect=1

# Enable DRM VC4 V3D driver
dtoverlay=vc4-kms-v3d
max_framebuffers=2

# Disable compensation for displays with overscan
disable_overscan=1

[cm4]
# Enable host mode on the 2711 built-in XHCI USB controller.
# This line should be removed if the legacy DWC2 controller is required
# (e.g. for USB device mode) or if USB support is not required.
otg_mode=1

[all]

[pi4]
# Run as fast as firmware / board allows
arm_boost=1

[all]

# Allow ssh over usb
dtoverlay=dwc2

# Enable RTC clock module 
dtoverlay=i2c-rtc,ds3231

# Enable UART1 so GPIO14 can be used as LED status indicator for Pi
enable_uart=1

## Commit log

2022-09-24 all configuration files modified for pigarden added
    [config.txt]
2022-09-26 HW BoM file added to ./hw directory
2022-09-28 test/buzzer_on_off.py test script added
    [buzzer_on_off.py]
2022-09-28 buzzer sound to anounce controller boot finish added, comment modified instide ./test/buzzer_on_of.py made
    [buzzer_on_off.py, solarcalc.py]
2022-09-30 ./test/buzzer_on_off.py test routine added, BuzzerSound function updated in solarcalc.py
    [solarcalc.py]
2022-09-30 test routinge ./test/buzzer_on_off added
    [buzzer_on_off.py]
2022-09-30 beep routines re-designed in both test/buzzer_on_off.py and src/solarcalc.py
    [buzzer_on_off.py, solarcalc.py]
2022-10-01 bug <Light Switch toggle does not counted by shutdown procedure #11> corrected
    [solarcalc.py]
2022-10-01 further enhancment of bug fix: <Light Switch toggle does not counted by shutdown procedure #11> first beep heart even when pi boots with ligth switch on
    [solarcalc.py]
2022-10-01 logging in src/solarcalc.py, button handling threat improved
2022-10-02 first version of hw bom created at ./docs/gardenpi_bom.txt
2022-10-02 HW BoM updated
2022-10-04 added support for status indication on GPIO14 (TX UART1)
    [config.txt]
2022-10-04 schematics files added to /doc directory, README.md updated with hyperlinks and cleaned up further
    [gardenpi_schematics.fzz]
2022-10-22 configuration files updated, timers in prometheus.yml file updated
2022-10-23 ligth status reporting to prometheus corrected, location info reporting added
    [build_prom_file.py, solarcalc.py]
2022-10-23 error in PromMetrixSet corrected - lightstatus value
    [solarcalc.py]
2022-10-30 schematics, bom and cmd file updated to reflect gui/buzzer support
    [gardenpi_schematics.fzz]
2022-10-30 bom header corrected
2022-11-01 issues fixed: use of depreciated zone function call from tzlocal module and time printed with too high precission in info trace
    [daylightsavingtime.py, solarcalc.py]
2022-12-03 Power socket changed, readme,bom, gardenpi cmd and hw pictures updated
2022-12-03 revision stepped to 5.0 in hw bom file
